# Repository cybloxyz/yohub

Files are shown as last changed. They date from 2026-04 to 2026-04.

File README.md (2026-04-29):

# YOHUB v0.1.0
meet YOHUBv0.1.0! a compact size dual function of hardware! aesthetic and usable as an USB HUB!
this USB hub was deisgned with kicad

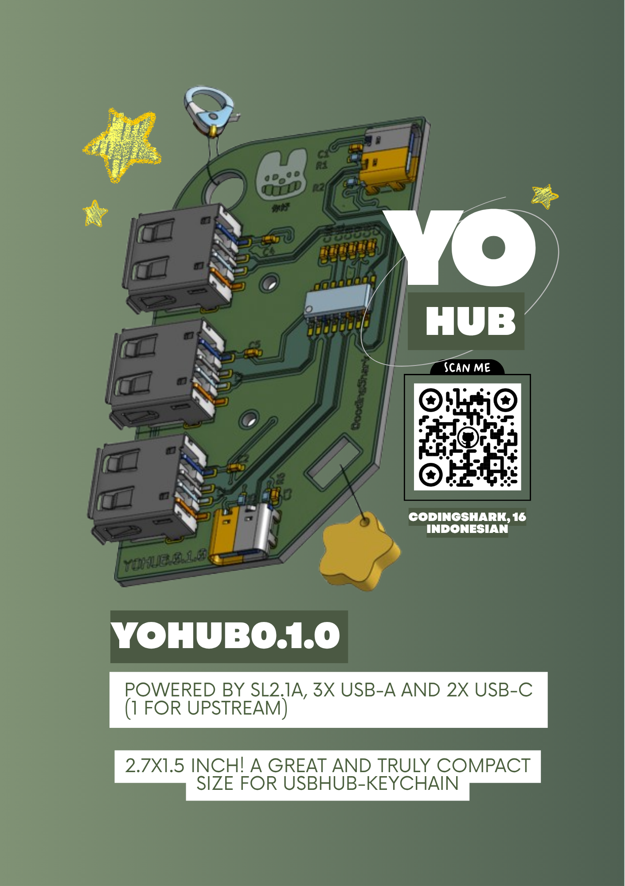
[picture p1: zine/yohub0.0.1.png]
zine


## why?
i made this immediately after my laptop's touchpad broken, i realize that i only have one USB port and it is already taken for my mouse, i confuse how do i attach the flashdrive or anything else.

## what is this?
keychain that you could use as an usual USB Hub, powered by SL2.1A! really compact and suitable for any bag ofc :3 oh and it also has transparent case! a YoCase

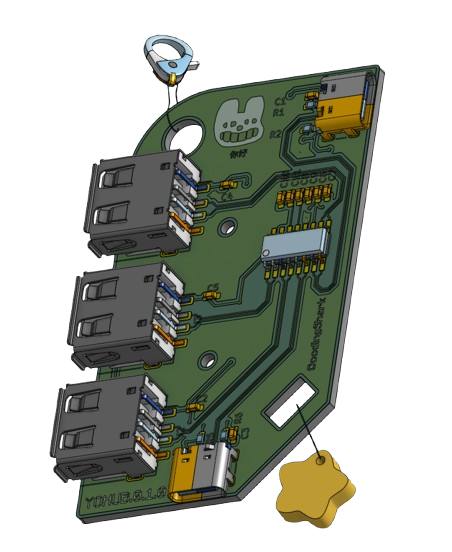
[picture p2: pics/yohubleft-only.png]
yohub
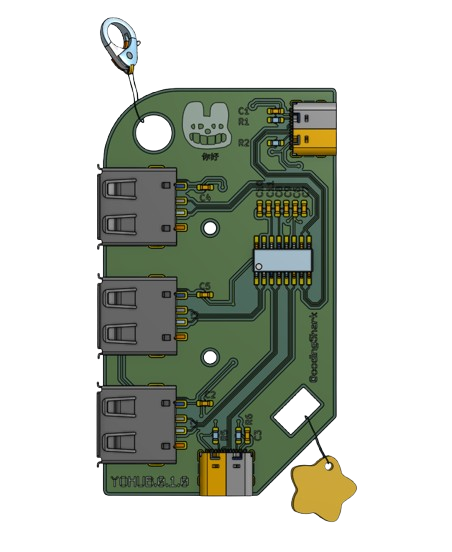
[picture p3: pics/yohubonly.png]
yohub
 
and here is the YoCase version
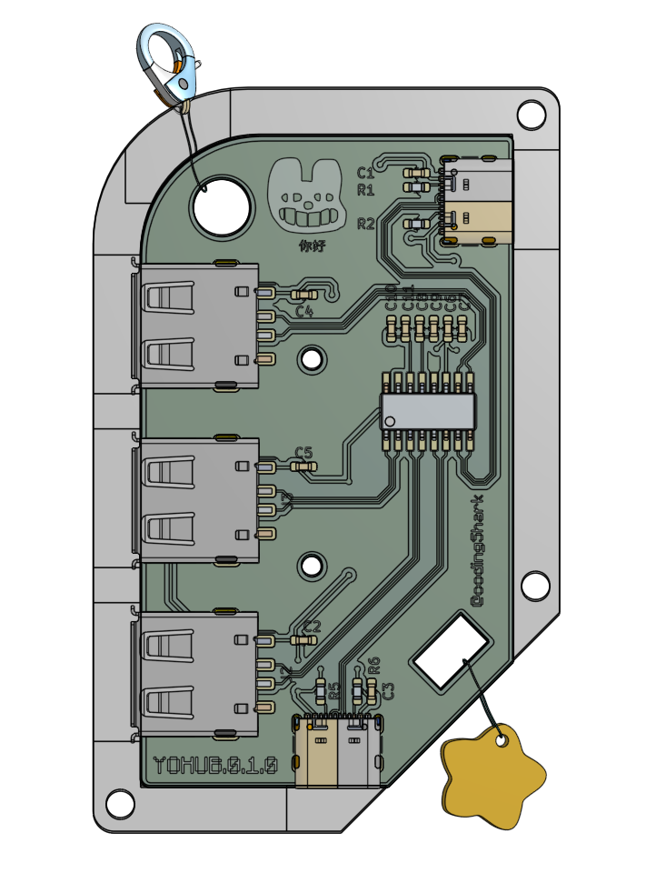
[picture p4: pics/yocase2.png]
yohub with case


here are some features of YOHUB v0.1.0

> 3x USB-A

> 1x USB-C

> 1x USB-c as upstream port

> keychain hole

> compact size! 6.8x3.8 (in cm)

## schema and pcb
here is the screenshot of schema and pcb editor
here is the wiring diagram of Yohub, followed guide but i made the USB_A more than the USB_C since my laptop is lack of USB_A but have 3 port of USB_C.
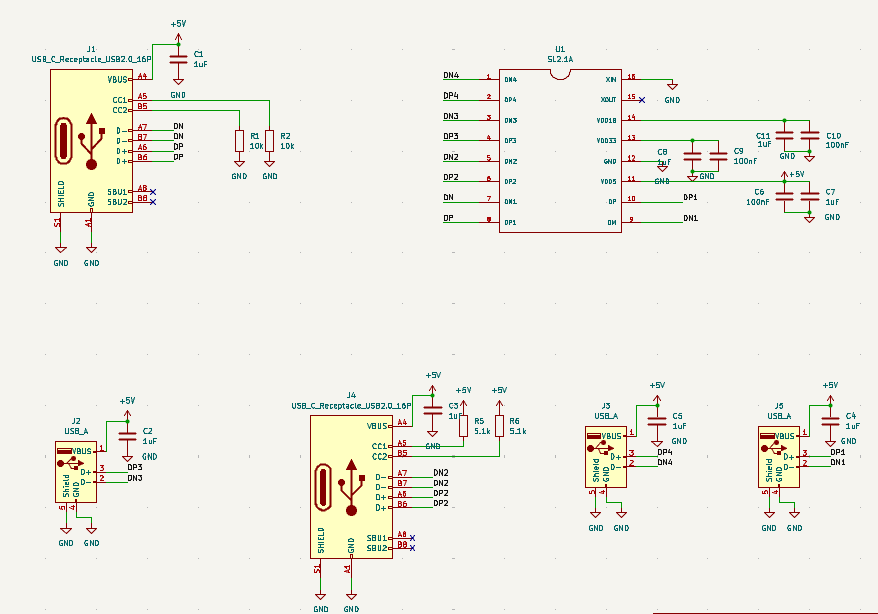
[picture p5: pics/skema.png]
schema

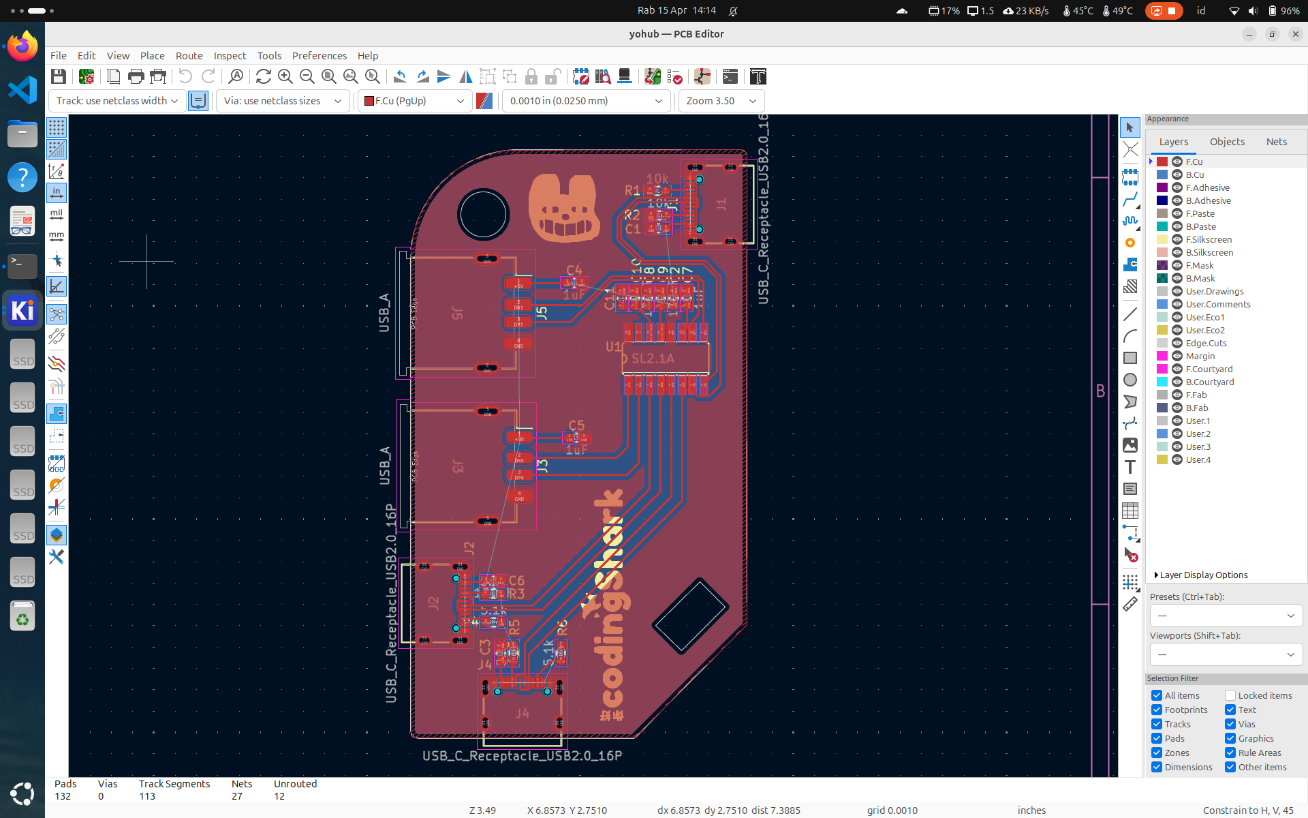
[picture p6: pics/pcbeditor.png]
pcb editor


## components
| Id | Designator | Footprint | Qty | Description | Supplier | Part Number | Price/Unit (IDR) | Total (IDR) | Link |
|:--:|:---|:---|:--:|:---|:---|:---|:---:|:---:|:---|
| 1 | C1, C2, C3, C4, C5, C7, C8, C11 | 0603 | 8 | 1uF Capacitor | LCSC | C15849 | 150 | 1.200 | [🔗 Link](https://www.lcsc.com/product-detail/C15849.html) |
| 2 | U1 | SO16 | 1 | SL2.1A (USB Hub IC) | LCSC | C92463 | 4.500 | 4.500 | [🔗 Link](https://www.lcsc.com/product-detail/C92463.html) |
| 3 | C6, C9, C10 | 0603 | 3 | 100nF Capacitor | LCSC | C14663 | 100 | 300 | [🔗 Link](https://www.lcsc.com/product-detail/C14663.html) |
| 4 | J1, J4 | USB-C 16P | 2 | USB-C Female GCT | LCSC | C719112 | 3.500 | 7.000 | [🔗 Link](https://www.lcsc.com/product-detail/C719112.html) |
| 5 | R1, R2 | 0603 | 2 | 10k Resistor | LCSC | C25804 | 50 | 100 | [🔗 Link](https://www.lcsc.com/product-detail/C25804.html) |
| 6 | R5, R6 | 0603 | 2 | 5.1k Resistor | LCSC | C25905 | 50 | 100 | [🔗 Link](https://www.lcsc.com/product-detail/C25905.html) |
| 7 | J2, J3, J5 | USB_A_Rec | 3 | USB 2.0 Type A | LCSC | C51922 | 2.500 | 7.500 | [🔗 Link](https://www.lcsc.com/product-detail/C51922.html) |
| | | | | **ESTIMASI TOTAL** | | | | **Rp20.700** | |

note: this is only the component not the pcb, we recommend to use JLCPCB

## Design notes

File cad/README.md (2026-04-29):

this is the onshape link

## disclaimer
the 3D printable part is only the YOCASE (yohub case), yohub itself is a PCB (it is also 3d printed but ofc different from the case).

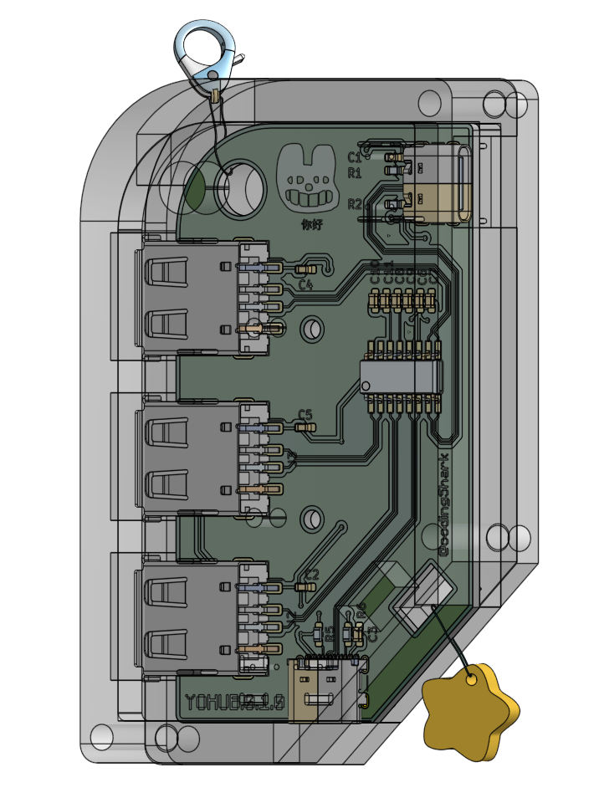
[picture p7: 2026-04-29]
pics/yocase.png

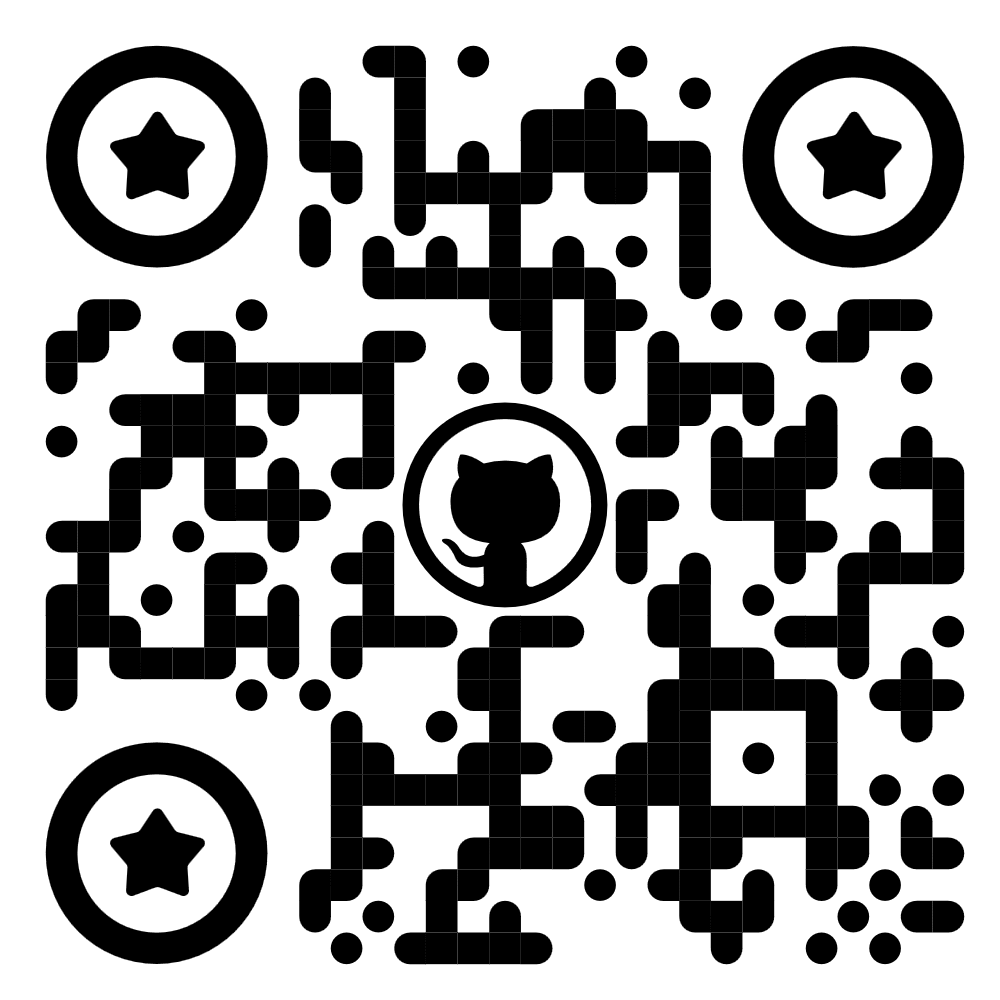
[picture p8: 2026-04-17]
pics/yohub-qr.png

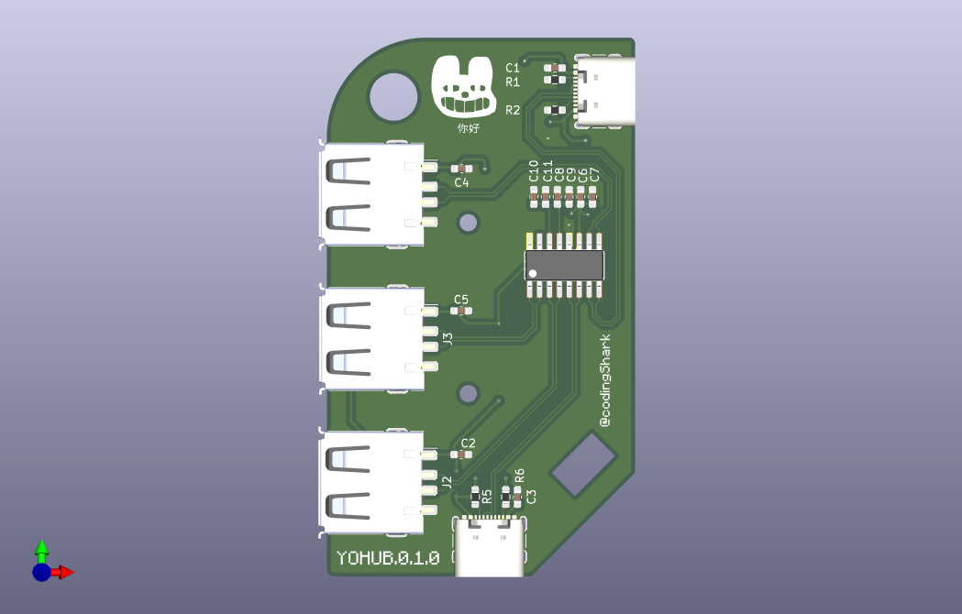
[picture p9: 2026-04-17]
pics/yohub.png

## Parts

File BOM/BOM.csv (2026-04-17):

Id | Designator | Qty | Description | LCSC_Ref | URL | Price_Unit_IDR | Total_IDR
1 | C2,C7,C5,C3,C4,C1,C11,C8 | 8 | 1uF Cap | C15849 | https://www.lcsc.com/product-detail/C15849.html | 150 | 1200
2 | U1 | 1 | SL2.1A IC | C92463 | https://www.lcsc.com/product-detail/C92463.html | 4500 | 4500
3 | C10,C6,C9 | 3 | 100nF Cap | C14663 | https://www.lcsc.com/product-detail/C14663.html | 100 | 300
4 | J1,J4 | 2 | USB-C 16P | C719112 | https://www.lcsc.com/product-detail/C719112.html | 3500 | 7000
5 | R2,R1 | 2 | 10k Res | C25804 | https://www.lcsc.com/product-detail/C25804.html | 50 | 100
6 | R5,R6 | 2 | 5.1k Res | C25905 | https://www.lcsc.com/product-detail/C25905.html | 50 | 100
7 | J3,J5,J2 | 3 | USB A Rec | C51922 | https://www.lcsc.com/product-detail/C51922.html | 2500 | 7500

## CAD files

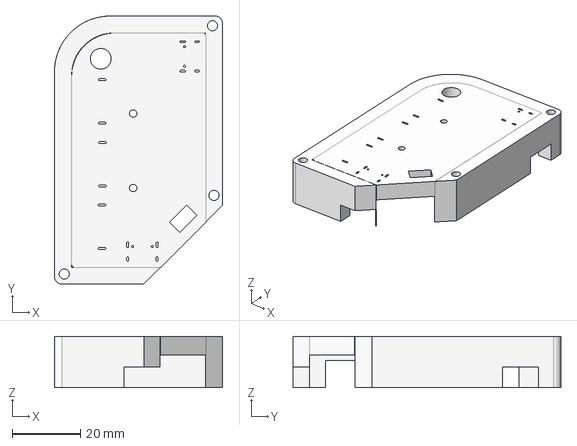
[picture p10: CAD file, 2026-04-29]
cad/STEPFILES/YOCASE/yohub parts - Part 65.step
49.4 x 78.8 x 15.1 mm

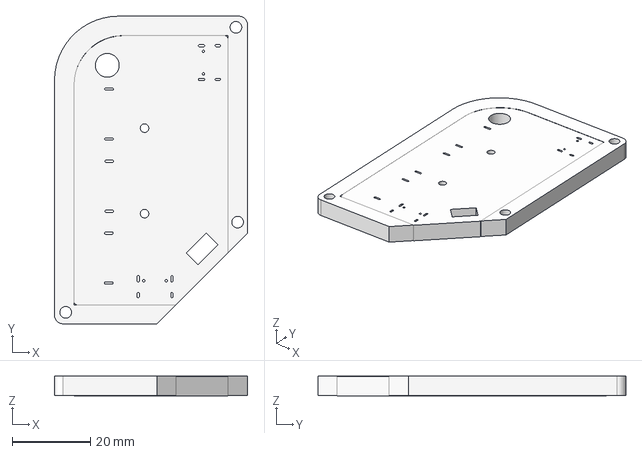
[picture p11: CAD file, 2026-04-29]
cad/STEPFILES/YOCASE/yohub parts - Part 64.step
49.4 x 78.8 x 5.05 mm

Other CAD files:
cad/YOCASE_STL/yohub parts - Part 64.stl
cad/YOCASE_STL/yohub parts - Part 65.stl

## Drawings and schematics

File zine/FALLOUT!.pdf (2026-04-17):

# YOHUB

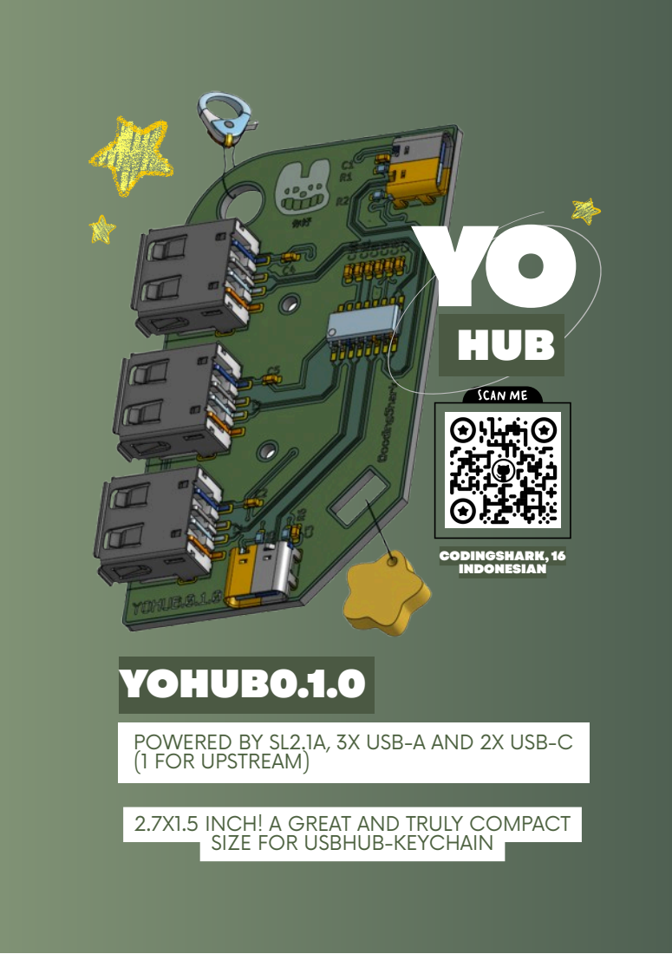
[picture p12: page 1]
YOHUB0.1.0; CODINGSHARK, 16 INDONESIAN

POWERED BY SL2.1A, 3X USB-A AND 2X USB-C
(1 FOR UPSTREAM)

2.7X1.5 INCH! A GREAT AND TRULY COMPACT

SIZE FOR USBHUB-KEYCHAIN

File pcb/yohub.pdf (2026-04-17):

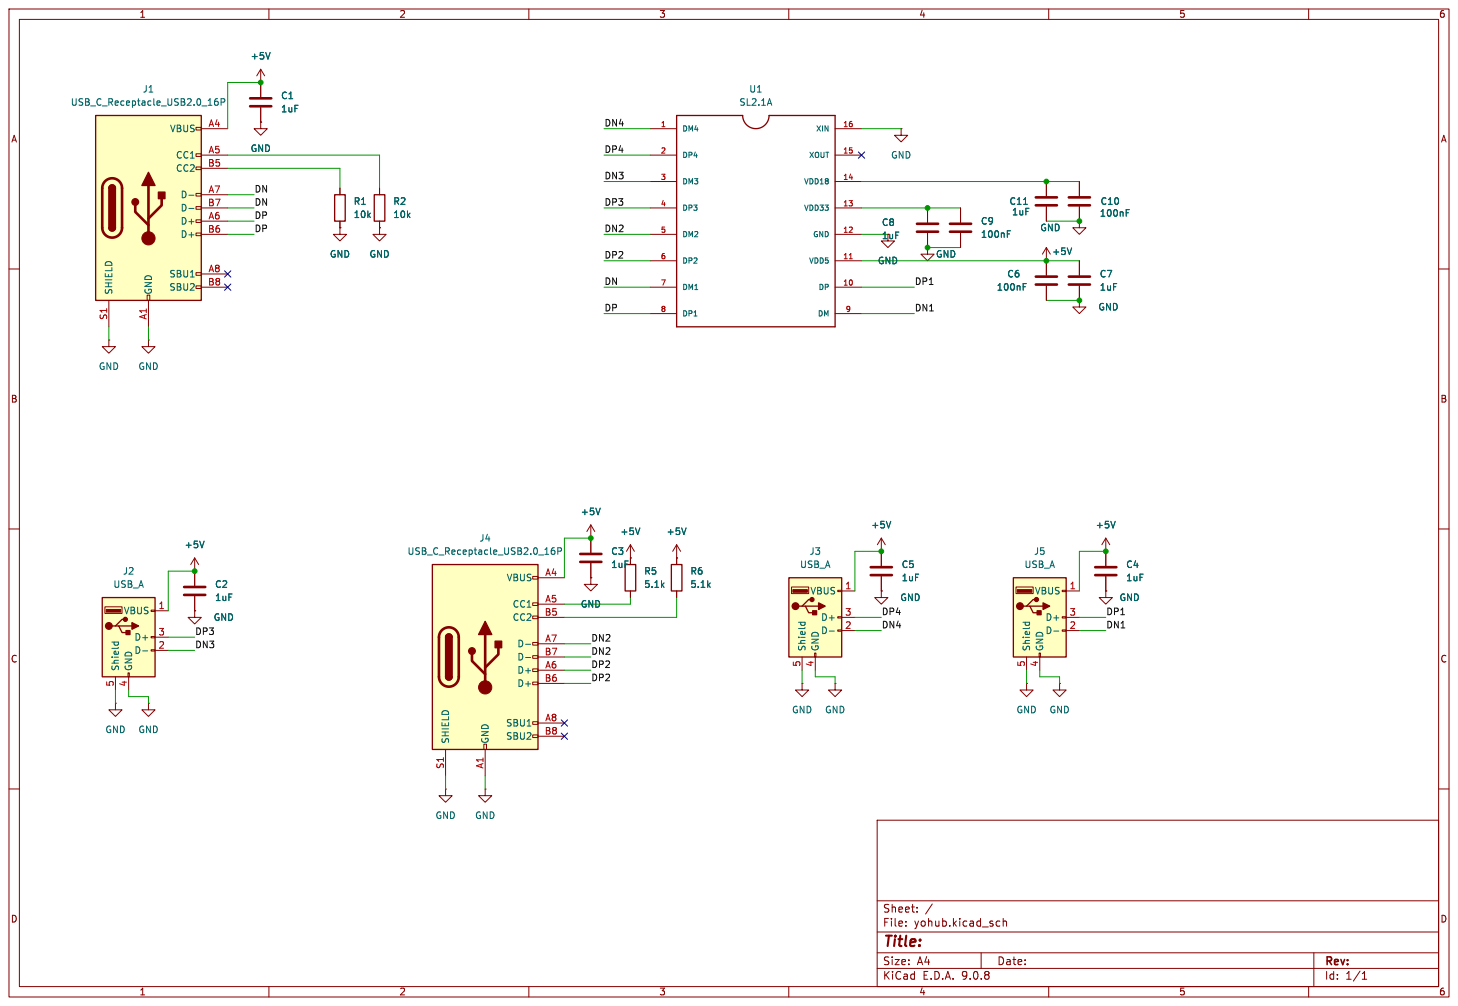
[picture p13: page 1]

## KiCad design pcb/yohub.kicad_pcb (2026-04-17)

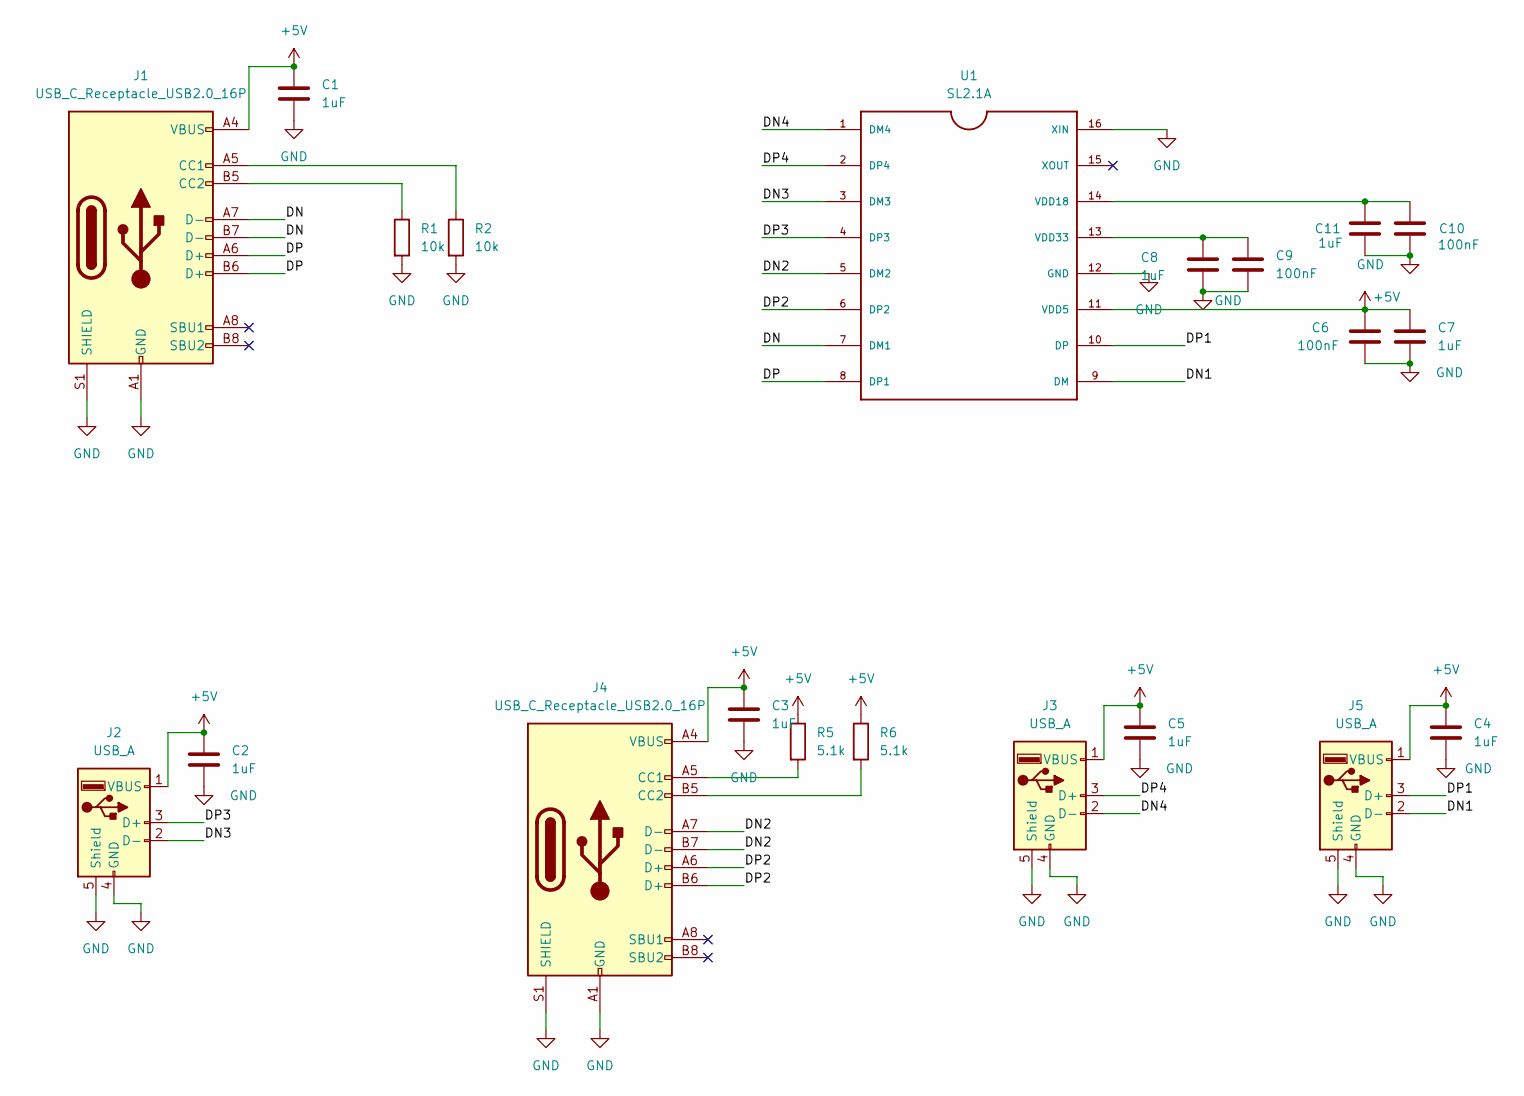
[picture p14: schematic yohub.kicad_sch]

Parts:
C1, C2, C3, C4, C5, C7, C8, C11: 1uF; C_0603_1608Metric_Pad1.08x0.95mm_HandSolder
C6, C9, C10: 100nF; C_0603_1608Metric_Pad1.08x0.95mm_HandSolder
J1, J4: USB_C_Receptacle_USB2.0_16P; USB_C_Receptacle_GCT_USB4105-xx-A_16P_TopMnt_Horizontal
J2, J3, J5: USB_A; USB_A_Receptacle_GCT_USB1046
R1, R2: 10k; R_0603_1608Metric_Pad0.98x0.95mm_HandSolder
R5, R6: 5.1k; R_0603_1608Metric_Pad0.98x0.95mm_HandSolder
U1: SL2.1A; SO16

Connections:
+5V: C1.1, C2.1, C3.1, C4.1, C5.1, C6.1, C7.1, J1.A4 (VBUS), J1.A9 (VBUS), J1.B4 (VBUS), J1.B9 (VBUS), J2.1 (VBUS), J3.1 (VBUS), J4.A4 (VBUS), J4.A9 (VBUS), J4.B4 (VBUS), J4.B9 (VBUS), J5.1 (VBUS), R5.1, R6.1, U1.11 (VDD5)
/DN: J1.A7 (D-), J1.B7 (D-), U1.7 (DM1)
/DN1: J5.2 (D-), U1.9 (DM)
/DN2: J4.A7 (D-), J4.B7 (D-), U1.5 (DM2)
/DN3: J2.2 (D-), U1.3 (DM3)
/DN4: J3.2 (D-), U1.1 (DM4)
/DP: J1.A6 (D+), J1.B6 (D+), U1.8 (DP1)
/DP1: J5.3 (D+), U1.10 (DP)
/DP2: J4.A6 (D+), J4.B6 (D+), U1.6 (DP2)
/DP3: J2.3 (D+), U1.4 (DP3)
/DP4: J3.3 (D+), U1.2 (DP4)
GND: C1.2, C2.2, C3.2, C4.2, C5.2, C6.2, C7.2, C8.2, C9.2, C10.2, C11.2, J1.A1 (GND), J1.A12 (GND), J1.B1 (GND), J1.B12 (GND), J1.S1 (SHIELD), J2.4 (GND), J2.5 (Shield), J3.4 (GND), J3.5 (Shield), J4.A1 (GND), J4.A12 (GND), J4.B1 (GND), J4.B12 (GND), J4.S1 (SHIELD), J5.4 (GND), J5.5 (Shield), R1.2, R2.2, U1.12 (GND), U1.16 (XIN)
unnamed: J1.A5 (CC1), R2.1
unnamed: J1.B5 (CC2), R1.1
unnamed: J4.A5 (CC1), R5.2
unnamed: J4.B5 (CC2), R6.2
unnamed: C10.1, C11.1, U1.14 (VDD18)
unnamed: C8.1, C9.1, U1.13 (VDD33)

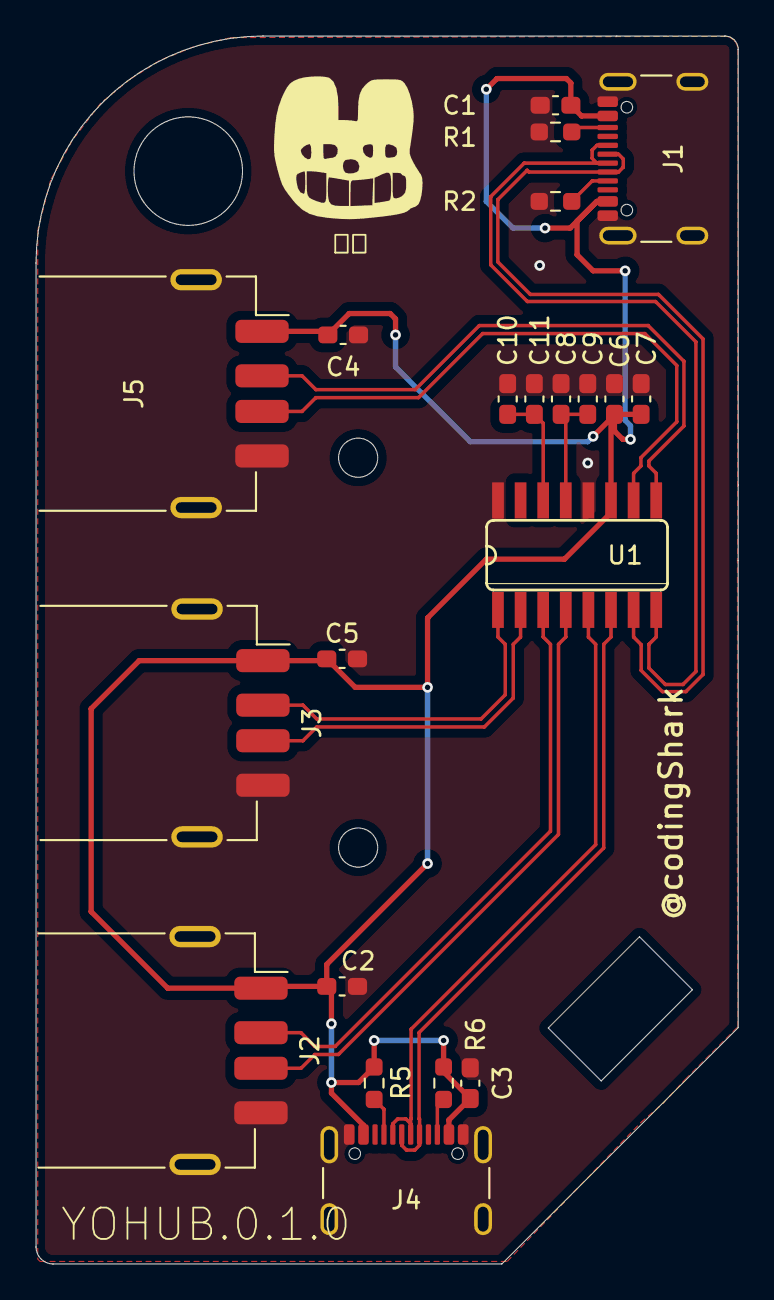
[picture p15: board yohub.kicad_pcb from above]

Board: 2 copper layers, 39.4 x 69.0 mm, 22 parts (0 on the bottom side), 18 nets.

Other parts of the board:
head: mao; head

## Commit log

2026-04-16 first initialize
    [yohub.kicad_pcb, yohub.kicad_sch, yohub.step]
2026-04-17 almost done!
    [yohub-B_Cu.gbr, yohub-B_Mask.gbr, yohub-B_Paste.gbr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]
2026-04-17 readme readme readme
    [BOM.csv]
2026-04-17 add links!
    [BOM.csv]
2026-04-29 add case and it called YoCase
    [yohub parts - Part 64.step, yohub parts - Part 64.stl, yohub parts - Part 65.step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]
